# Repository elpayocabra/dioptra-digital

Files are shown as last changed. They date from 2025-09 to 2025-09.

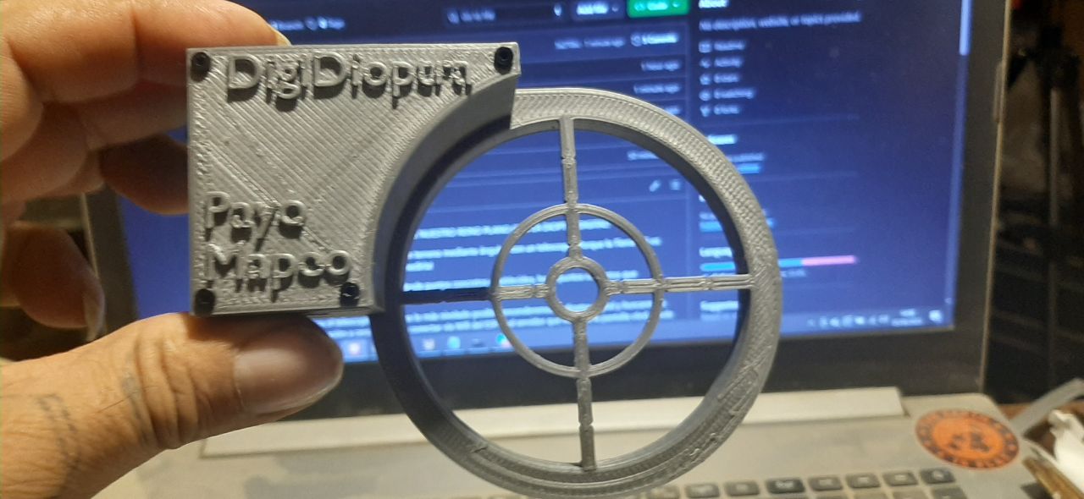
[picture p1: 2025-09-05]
photo_2025-09-05_14-11-05.jpg

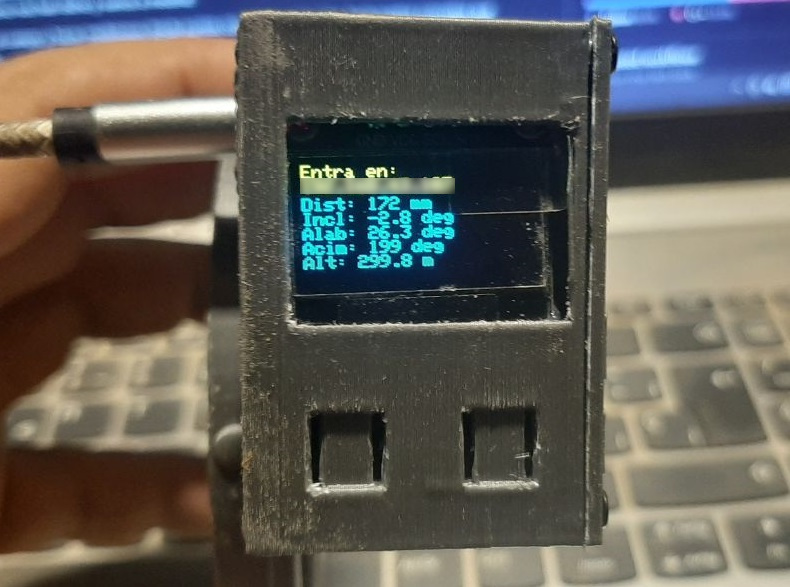
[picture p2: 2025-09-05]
photo_2025-09-05_14-11-04 (3).jpg

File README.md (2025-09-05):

PAYOMAPEO! CREA MAPAS TOPOGRÁFICOS DE NUESTRO REINO PLANO CON LA DIOPTRA DIGITAL!

 Este es un proyecto para hacer mediciones en terreno mediante ángulos con un telescopio. Porque la Tierra NO es una pelota como nos han dicho y vamos a medirla!

 La idea es ir al campo y hacer mediciones desde puntos concretos establecidos, hacia puntos concretos que observemos.

 Primero pondremos el telescopio en terreno lo más nivelado posible, encenderemos la dioptra digital y buscaremos ponerlo con la inclinación a cero. Se puede conectar vía Wifi del ESP32 al servidor que muestra la pantalla oled, desde ahí tendremos acceso a todas las funciones, si no, podemos anotar a mano los datos de la pantalla oled para cada punto observado.

 Desde la web, una vez que tengamos el telescopio con inclinación cero presionamos el botón "Guardar distancia al suelo", esto guardará la distandia que hay desde el centro de la retícula hasta el suelo para tener el dato de la altura del observador.

 Después, apuntamos hacia el punto que queramos, le ponemos un nombre al punto observado y presionamos el botón para guardar los datos de ese punto. Abajo del todo se actualizará una lista con los puntos que vayamos anotando, también puedes descargarlo en formato CSV.

 Una vez que hayas recopilado datos en el terreno puedes introducirlos en blender mediante el addon que acompaño aquí.

¿CÓMO FUNCIONA EL ADDON DE BLENDER?
--------------------------
 Con el addon puedes volcar los datos recogidos en el campo y establecer distancias automáticamente hacia los puntos observados.

 Primero creas la estación principal desde la que harás observaciones y luego vas creando los puntos observados dependiendo de los ángulos recogidos. Si no se establece una distancia concreta aparecerá un rayo de visión "infinito" el cual quedará ahí hasta que otro rayo lo intersecte y entonces aparecerán automáticamente las distancias calculadas por trigonometría.

 Los puntos observados también pueden convertirse en puntos de observación simplemente eligiéndolos por su nombre en el desplegable. De esta manera podemos ir formando una red y mapear distancias tan grandes como queramos.

 Se puede aplicar o no la declinación magnética, establecer un margen de error para las intersecciones de los rayos o también crear líneas manualmente eligiendo dos puntos.

HARDWARE
--------------------------
 Consta de una retícula para adaptar a un telescopio en el archivo "RETICULA DIOPTRA.STL" (deberás revisar las medidas de la punta de tu telescopio para adaptar el archivo STL a ellas).

 Dentro de la caja tendrás que acomodar la electrónica teniendo en cuenta de pegar el MPU6050 lo más horizontal posible en una de las "lejas" que hay dentro de la carcasa. Trata de que el magnetrómetro también esté bien alineado. Si no puedes mantener la orientación por defecto de estos módulos por cuestiones de montaje deberás modificar el código teniendo en cuenta tu configuración, he dejado anotaciones en las líneas correspondientes.

También debes poner tus datos propios para la red Wifi y la contraseña.

LISTA DE COMPONENTES
----------------------------------

-ESP32 C3 Supermini (procesador)
-MPU6050 (acelerómetro/ giroscopio de 3 ejes)
-GY-271 (magnetómetro de 3 ejes)
-BMP280 (sensor de altitud/ presión/ temperatura)
-Pantalla Oled 0.96"
-VL53L0X (sensor de distancia)

-Retícula STL y su tapa (adjuntos) 
-4 tornillos M2x6
-4 tuercas de inserción M2 

-No lleva batería, por lo que debemos conectarla a un powerbank!

SOFTWARE
--------------------------

-Código .ino para el ESP32 C3
-Addon para Blender

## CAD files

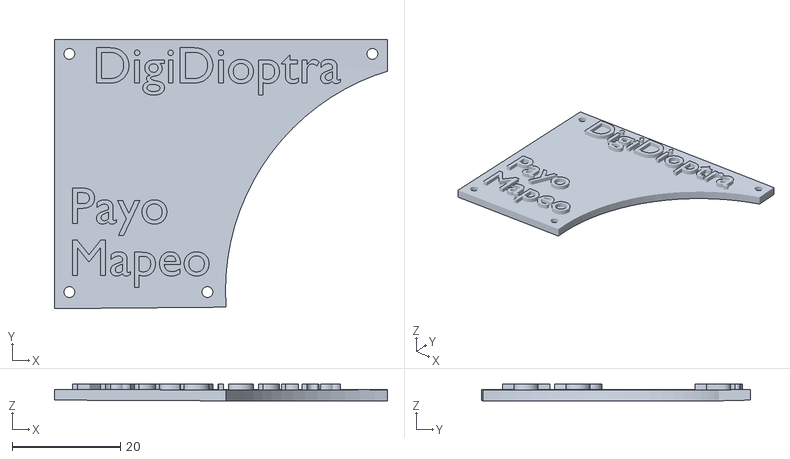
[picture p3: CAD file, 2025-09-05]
TAPA DIOPTRA.stl
61.5 x 49.8 x 3.09

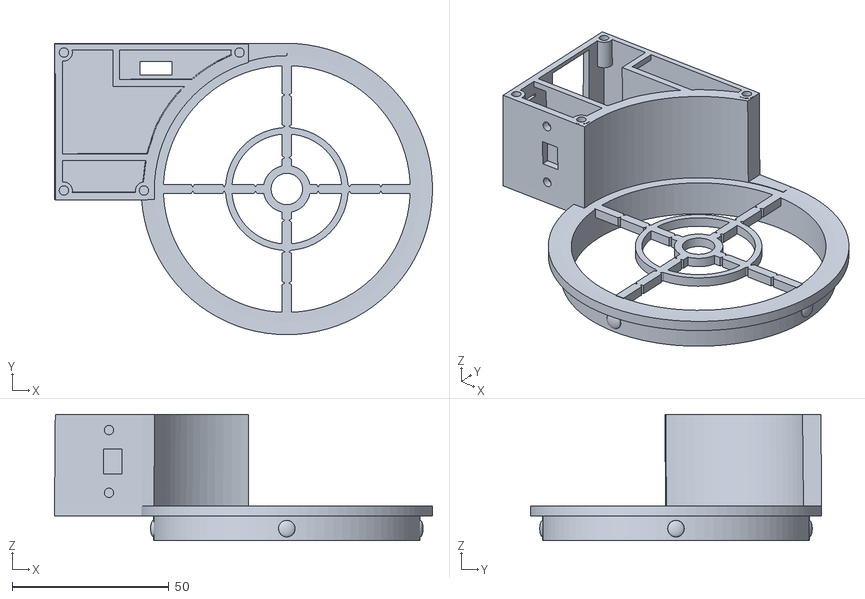
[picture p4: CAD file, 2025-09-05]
RETICULA DIOPTRA.stl
120.5 x 92.9 x 40.3

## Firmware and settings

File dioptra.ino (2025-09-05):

#include <Wire.h>
#include <Adafruit_GFX.h>
#include <Adafruit_SSD1306.h>
#include <Adafruit_MPU6050.h>
#include <Adafruit_Sensor.h>
#include <VL53L0X.h>
#include <QMC5883LCompass.h>
#include <Adafruit_BMP280.h>
#include <WiFi.h>
#include <WebServer.h>

// ------------------- CONFIGURACIÓN OLED -------------------
#define SCREEN_WIDTH 128
#define SCREEN_HEIGHT 64
Adafruit_SSD1306 display(SCREEN_WIDTH, SCREEN_HEIGHT, &Wire, -1);

// ------------------- SENSORES -------------------
VL53L0X tof;
Adafruit_MPU6050 mpu;
QMC5883LCompass compass;
Adafruit_BMP280 bmp;

// ------------------- PINES I2C ESP32-C3 SuperMini -------------------
#define SDA_PIN 8
#define SCL_PIN 9

// ------------------- WIFI -------------------
const char* ssid = "******"; //PON TU PROPIA RED WIFI <<<<<<<<<<<<<<<<<<<<<<<<<<<<<<<<<<<<<<<<<<<<<<<<<<<<<<<< OJO AQUÍ!
const char* password = "******"; //PON LA CONTRASEÑA DE TU RED WIFI <<<<<<<<<<<<<<<<<<<<<<<<<<<<<<<<<<<<<<<<<<<<<<<<<<<<<<<< OJO AQUÍ!
WebServer server(80);

// ------------------- VARIABLES GLOBALES -------------------
uint16_t distance;
float roll, pitch;
int heading;
float altitude;
float tempMPU, tempBMP, presionBMP;

// Variables para la funcionalidad web
uint16_t distanciaSueloCalibrada = 0;
String datosGuardados =
  "Punto,Distancia(mm),Inclinacion(deg),Alabeo(deg),Acimut(deg),Altitud(m),"
  "TempMPU(C),TempBMP(C),Presion(hPa),DistSueloCalibrada(mm)\n";

// ------------------- DECLARACIÓN DE FUNCIONES DEL SERVIDOR WEB -------------------
void handleRoot();
void handleCalibrar();
void handleGuardar();
void handleDownload();
void handleLimpiar();
void handleJSON();

// ------------------- FUNCIÓN PRINCIPAL DE LA PÁGINA WEB -------------------
void handleRoot() {
  String html = "<!DOCTYPE html><html><head><meta charset='utf-8'><meta name='viewport' "
                "content='width=device-width,initial-scale=1'>";
  html += "<title>PayoMapeo Web</title>";
  html += "<style>body{font-family:sans-serif;background-color:#f0f0f0;color:#333;"
          "max-width:800px;margin:0 auto;padding:15px;}"
          "h1,h2{color:#0056b3;}div{background-color:white;padding:20px;margin-bottom:20px;"
          "border-radius:8px;box-shadow:0 2px 4px rgba(0,0,0,0.1);} "
          "input[type='text'],input[type='submit']{padding:10px;margin-top:5px;border-radius:5px;"
          "border:1px solid #ccc;width:calc(100% - 22px);} "
          "input[type='submit']{background-color:#007bff;color:white;cursor:pointer;font-weight:bold;} "
          "a{text-decoration:none;display:inline-block;padding:10px 15px;background-color:#28a745;"
          "color:white;font-weight:bold;border-radius:5px;text-align:center;} "
          "pre{white-space:pre-wrap;word-wrap:break-word;background-color:#eee;padding:10px;border-radius:5px;}</style>";
  html += "</head><body>";
  html += "<h1>PayoMapeo Visor De Datos</h1>";

  // --- Lecturas en tiempo real ---
  html += "<div><h2>Lecturas en tiempo real</h2>";
  html += "<p><b>Distancia:</b> <span id='distancia'>--</span> mm</p>";
  html += "<p><b>Inclinación (Roll):</b> <span id='inclinacion'>--</span> &deg;</p>";
  html += "<p><b>Alabeo (Pitch):</b> <span id='alabeo'>--</span> &deg;</p>";
  html += "<p><b>Acimut:</b> <span id='acimut'>--</span> &deg;</p>";
  html += "<p><b>Altitud:</b> <span id='altitud'>--</span> m</p>";
  html += "<p><b>Temp. MPU6050:</b> <span id='tempmpu'>--</span> &deg;C</p>";
  html += "<p><b>Temp. BMP280:</b> <span id='tempbmp'>--</span> &deg;C</p>";
  html += "<p><b>Presión BMP280:</b> <span id='presion'>--</span> hPa</p></div>";

  // --- Calibración ---
  html += "<div><h2>Calibración</h2>";
  html += "<p>Apunta el telescopio nivelado al suelo y pulsa para guardar la distancia de referencia.</p>";
  html += "<p><b>Distancia al suelo guardada:</b> <span id='dist_calibrada'>--</span> mm</p>";
  html += "<form action='/calibrar' method='POST'><input type='submit' value='Guardar distancia al suelo'></form></div>";

  // --- Guardar punto ---
  html += "<div><h2>Guardar Punto Observado</h2>";
  html += "<form action='/guardar' method='POST'>";
  html += "<label for='punto'>Nombre del punto:</label><br>";
  html += "<input type='text' id='punto' name='punto' placeholder='Ej: Estrella Polar' required>";
  html += "<input type='submit' value='Guardar datos del punto'></form></div>";

  // --- Datos guardados ---
  html += "<div><h2>Datos Guardados</h2>";
  html += "<p>Los puntos que guardes aparecerán aquí. Puedes descargarlos como un archivo CSV.</p>";
  html += "<a href='/download' download='datos_telescopio.csv'>Descargar Datos (CSV)</a>";
  html += "<form action='/limpiar' method='POST' style='margin-top:10px;'><input type='submit' value='Limpiar todos los datos' style='background-color:#dc3545;'></form>";
  html += "<h3>Ficha de datos:</h3><pre>" + datosGuardados + "</pre></div>";

  // --- Script AJAX ---
  html += "<script>";
  html += "function actualizarDatos() {";
  html += "  fetch('/json')";
  html += "    .then(response => response.json())";
  html += "    .then(data => {";
  html += "      document.getElementById('distancia').innerText = data.distancia;";
  html += "      document.getElementById('inclinacion').innerText = data.inclinacion.toFixed(1);";
  html += "      document.getElementById('alabeo').innerText = data.alabeo.toFixed(1);";
  html += "      document.getElementById('acimut').innerText = data.acimut;";
  html += "      document.getElementById('altitud').innerText = data.altitud.toFixed(1);";
  html += "      document.getElementById('tempmpu').innerText = data.tempmpu.toFixed(1);";
  html += "      document.getElementById('tempbmp').innerText = data.tempbmp.toFixed(1);";
  html += "      document.getElementById('presion').innerText = data.presion.toFixed(1);";
  html += "      document.getElementById('dist_calibrada').innerText = data.distancia_suelo_calibrada;";
  html += "    })";
  html += "    .catch(error => console.error('Error al obtener datos:', error));";
  html += "}";
  html += "document.addEventListener('DOMContentLoaded', actualizarDatos);";
  html += "setInterval(actualizarDatos, 2000);";
  html += "</script>";

  html += "</body></html>";
  server.send(200, "text/html", html);
}

// ------------------- FUNCIONES WEB -------------------
void handleCalibrar() {
  distanciaSueloCalibrada = distance;
  server.sendHeader("Location", "/");
  server.send(303);
}

void handleGuardar() {
  if (server.hasArg("punto")) {
    String nombrePunto = server.arg("punto");
    String nuevaLinea = nombrePunto + "," + String(distance) + "," + String(roll, 1) + "," +
                        String(pitch, 1) + "," + String(heading) + "," + String(altitude, 1) + "," +
                        String(tempMPU, 1) + "," + String(tempBMP, 1) + "," + String(presionBMP, 1) +
                        "," + String(distanciaSueloCalibrada) + "\n";
    datosGuardados += nuevaLinea;
  }
  server.sendHeader("Location", "/");
  server.send(303);
}

void handleDownload() {
  server.sendHeader("Content-Disposition", "attachment; filename=datos_telescopio.csv");
  server.send(200, "text/csv", datosGuardados);
}

void handleLimpiar() {
  datosGuardados =
    "Punto,Distancia(mm),Inclinacion(deg),Alabeo(deg),Acimut(deg),Altitud(m),"
    "TempMPU(C),TempBMP(C),Presion(hPa),DistSueloCalibrada(mm)\n";
  server.sendHeader("Location", "/");
  server.send(303);
}

void handleJSON() {
  String json = "{";
  json += "\"distancia\":" + String(distance) + ",";
  json += "\"inclinacion\":" + String(roll, 1) + ",";
  json += "\"alabeo\":" + String(pitch, 1) + ",";
  json += "\"acimut\":" + String(heading) + ",";
  json += "\"altitud\":" + String(altitude, 1) + ",";
  json += "\"tempmpu\":" + String(tempMPU, 1) + ",";
  json += "\"tempbmp\":" + String(tempBMP, 1) + ",";
  json += "\"presion\":" + String(presionBMP, 1) + ",";
  json += "\"distancia_suelo_calibrada\":" + String(distanciaSueloCalibrada);
  json += "}";
  server.send(200, "application/json", json);
}

// ------------------- SETUP -------------------
void setup() {
  Serial.begin(115200);
  Wire.begin(SDA_PIN, SCL_PIN);

  if (!display.begin(SSD1306_SWITCHCAPVCC, 0x3C)) {
    Serial.println("OLED no encontrado!");
    for (;;);
  }
  display.clearDisplay();
  display.setTextSize(1);
  display.setTextColor(SSD1306_WHITE);
  display.setCursor(0, 0);
  display.println("Inicializando");
  display.setTextSize(2);
  display.setCursor(0, 16);
  display.println("PayoMapeo");
  display.display();

  if (!tof.init()) { Serial.println("VL53L0X no encontrado!"); while (1); }
  tof.setTimeout(500);

  if (!mpu.begin(0x68)) { Serial.println("MPU6050 no encontrado!"); while (1); }
  mpu.setAccelerometerRange(MPU6050_RANGE_4_G);
  mpu.setGyroRange(MPU6050_RANGE_500_DEG);
  mpu.setFilterBandwidth(MPU6050_BAND_21_HZ);

  compass.init();

  if (!bmp.begin(0x76)) { Serial.println("BMP280 no encontrado!"); while (1); }

  WiFi.begin(ssid, password);
  Serial.print("Conectando a WiFi...");
  while (WiFi.status() != WL_CONNECTED) { delay(500); Serial.print("."); }
  Serial.println("\nConectado a WiFi!");
  Serial.print("IP asignada: ");
  Serial.println(WiFi.localIP());

  server.on("/", handleRoot);
  server.on("/json", handleJSON);
  server.on("/calibrar", HTTP_POST, handleCalibrar);
  server.on("/guardar", HTTP_POST, handleGuardar);
  server.on("/download", handleDownload);
  server.on("/limpiar", HTTP_POST, handleLimpiar);

  server.begin();
  Serial.println("Servidor web iniciado");
}

// ------------------- LOOP -------------------
void loop() {
  distance = tof.readRangeSingleMillimeters();

  sensors_event_t a, g, temp;
  mpu.getEvent(&a, &g, &temp);
  roll  = -atan2(a.acceleration.y, a.acceleration.z) * 57.3; // MODIFICA AQUÍ SEGÚN HAYAS MONTADO TU MPU6050 PARA OBTENER VALORES POSITIVOS CUANDO SUBES EL TELESCOPIO. EL SIGNO MENOS ESTÁ INVIRTIENDO LA INCLINACIÓN, PUEDES QUITARLO
  pitch = atan(-a.acceleration.x /
               sqrt(a.acceleration.y * a.acceleration.y + a.acceleration.z * a.acceleration.z)) * 57.3;
  tempMPU = temp.temperature;

  compass.read();
  heading = (compass.getAzimuth() + 180) % 360;  // MODIFICA AQUÍ SEGÚN HAYAS MONTADO TU BRÚJULA, ESTA ESTÁ GIRADA 180 GRADOS

  altitude = bmp.readAltitude(1013.25);
  tempBMP = bmp.readTemperature();
  presionBMP = bmp.readPressure() / 100.0F;

  // --- OLED (sin cambios) ---
  display.clearDisplay();
  display.setTextSize(1);
  display.setCursor(0, 0);
  display.println("Entra en:");
  display.println(WiFi.localIP());
  display.print("Dist: "); display.print(distance); display.println(" mm");
  display.print("Incl: "); display.print(roll, 1); display.println(" deg");
  display.print("Alab: "); display.print(pitch, 1); display.println(" deg");
  display.print("Acim: "); display.print(heading); display.println(" deg");
  display.print("Alt: "); display.print(altitude, 1); display.println(" m");
  display.display();

  server.handleClient();
  delay(300);
}
